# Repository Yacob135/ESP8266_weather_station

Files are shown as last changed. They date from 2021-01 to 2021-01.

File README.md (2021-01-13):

# ESP8266_weather_station

This weather station has an ESP8266-12F in combination with DS18B20 and/or BME280 for sensing. I used a TP4056 module for 18650 Li-Ion battery charging/protection and TPS63900 buck-boost converter, which has incredibly low quiescent current combined with great efficiency at low power consumption (>90% at 10uA).

The station connects to my local Blynk server and sends the data every 5 minutes. During deep-sleep the whole circuit consumes about 25uA, which is fantastic. It should last about a year on one charge, since it connects to my server, sends the data and goes back to sleep in about 0.7s on average (I used Blynk API to reduce the connection time). So the overall power consumption is really low.

Just a little warning when buying ESP8266-12F modules from aliexpress. Make sure to buy the Ai-Thinker version, since the "Espressif" version will have about 150uA in deep-sleep instead of 20uA. Learnt this the hard way.

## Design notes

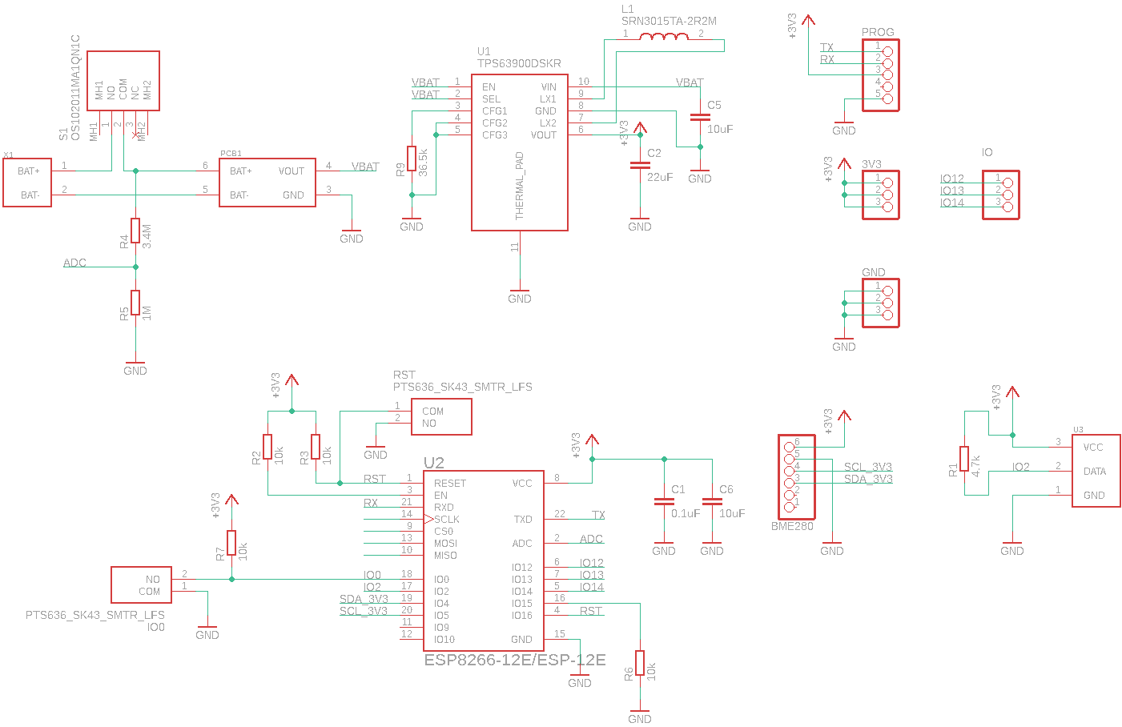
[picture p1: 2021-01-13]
ESP8266_weather_station_schematic.png

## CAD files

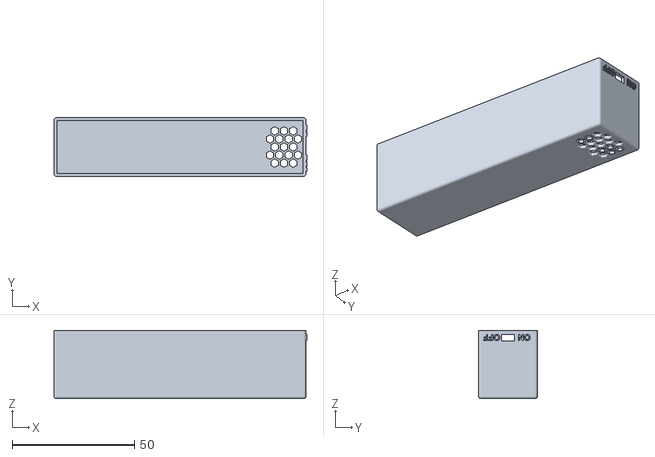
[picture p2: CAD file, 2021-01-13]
Main_body.stl
103.3 x 24.0 x 27.9

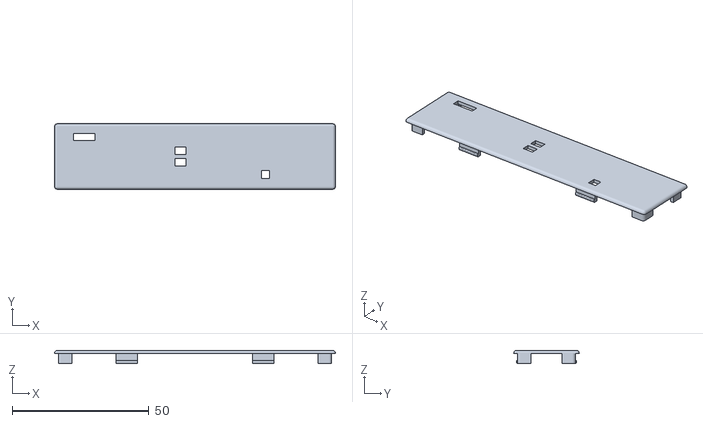
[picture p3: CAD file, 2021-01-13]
Top_cover.stl
102.9 x 24.0 x 4.80

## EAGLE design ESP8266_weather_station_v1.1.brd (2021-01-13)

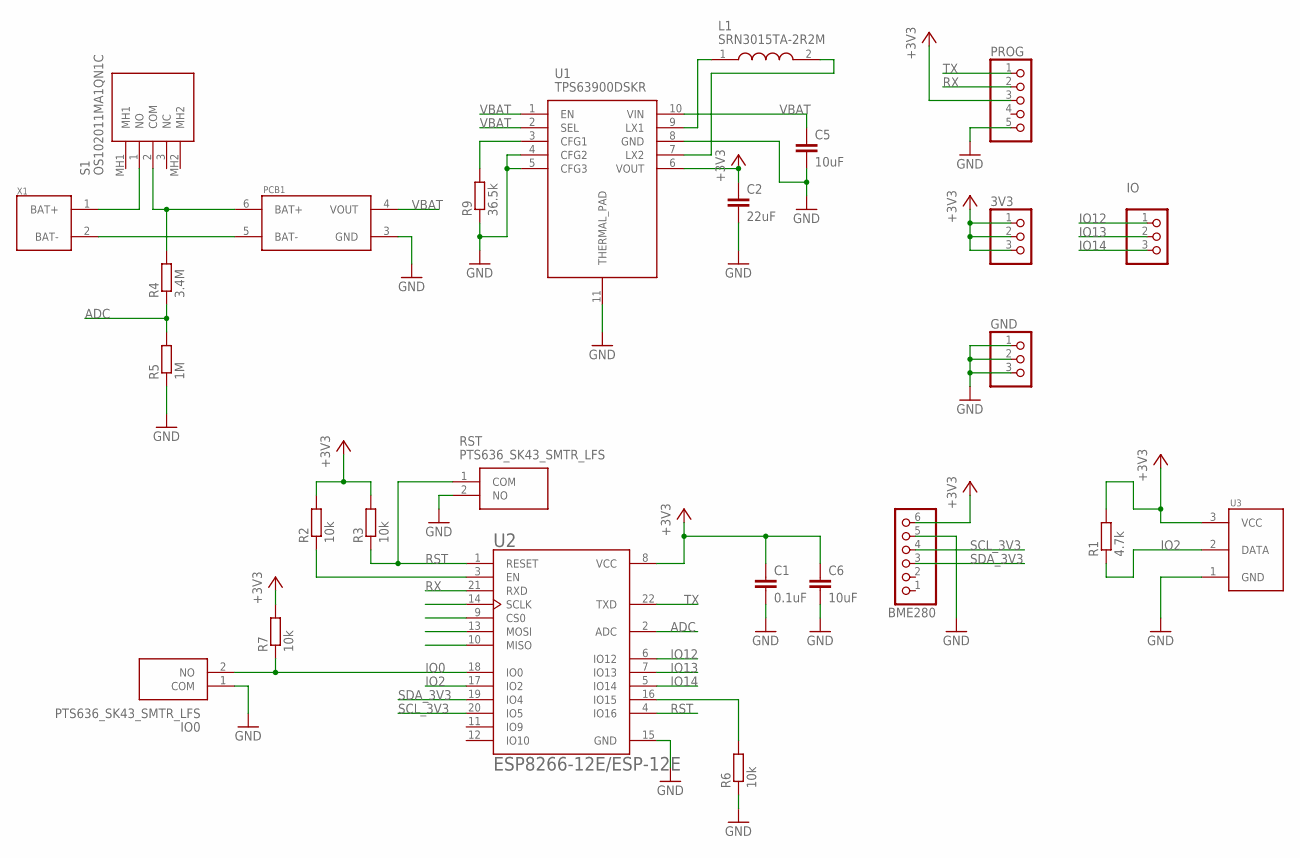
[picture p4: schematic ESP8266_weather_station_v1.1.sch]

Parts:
3V3: PINHD-1X3; 1X03
BME280: PINHD-1X6; 1X06
C1: 0.1uF; C0805
C2: 22uF; C0805
C5, C6: 10uF; C0805
GND: PINHD-1X3; 1X03
IO: PINHD-1X3; 1X03
IO0: PTS636_SK43_SMTR_LFS; PTS636SK43SMTRLFS
L1: SRN3015TA-2R2M; SRN3015TA2R2M
PCB1: TP4056_MODULE
PROG: PINHD-1X5; 1X05
R1: 4.7k; R0805
R2, R3, R6, R7: 10k; R0805
R4: 3.4M; R0805
R5: 1M; R0805
R9: 36.5k; R0805
RST: PTS636_SK43_SMTR_LFS; PTS636SK43SMTRLFS
S1: OS102011MA1QN1C
U1: TPS63900DSKR; SON50P250X250X80-11N
U2: ESP8266-12E/ESP-12E; XCVR_ESP8266-12E/ESP-12E
U3: DS18B20
X1: 18650_SMD_HOLDER

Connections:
+3V3: 3V3.1, 3V3.2, 3V3.3, BME280.6, C1.1, C2.1, C6.1, PROG.3, R1.2, R2.2, R3.2, R7.2, U1.6 (VOUT), U2.8 (VCC), U3.3 (VCC)
ADC: R4.1, R5.2, U2.2 (ADC)
GND: BME280.5, C1.2, C2.2, C5.2, C6.2, GND.1, GND.2, GND.3, IO0.1 (COM), PCB1.3 (GND), PROG.5, R5.1, R6.1, R9.1, RST.2 (NO), U1.4 (CFG2), U1.5 (CFG3), U1.8 (GND), U1.11 (THERMAL_PAD), U2.15 (GND), U3.1 (GND)
IO0: IO0.2 (NO), R7.1, U2.18 (IO0)
IO2: R1.1, U2.17 (IO2), U3.2 (DATA)
IO12: IO.1, U2.6 (IO12)
IO13: IO.2, U2.7 (IO13)
IO14: IO.3, U2.5 (IO14)
unnamed: S1.1 (NO), X1.1 (BAT+)
unnamed: R9.2, U1.3 (CFG1)
unnamed: PCB1.6 (BAT+), R4.2, S1.2 (COM)
unnamed: PCB1.5 (BAT-), X1.2 (BAT-)
unnamed: R6.2, U2.16 (IO15)
unnamed: L1.1, U1.9 (LX1)
unnamed: L1.2, U1.7 (LX2)
unnamed: R2.1, U2.3 (EN)
RST: R3.1, RST.1 (COM), U2.1 (RESET), U2.4 (IO16)
RX: PROG.2, U2.21 (RXD)
SCL_3V3: BME280.4, U2.20 (IO5)
SDA_3V3: BME280.3, U2.19 (IO4)
TX: PROG.1, U2.22 (TXD)
VBAT: C5.1, PCB1.4 (VOUT), U1.1 (EN), U1.2 (SEL), U1.10 (VIN)

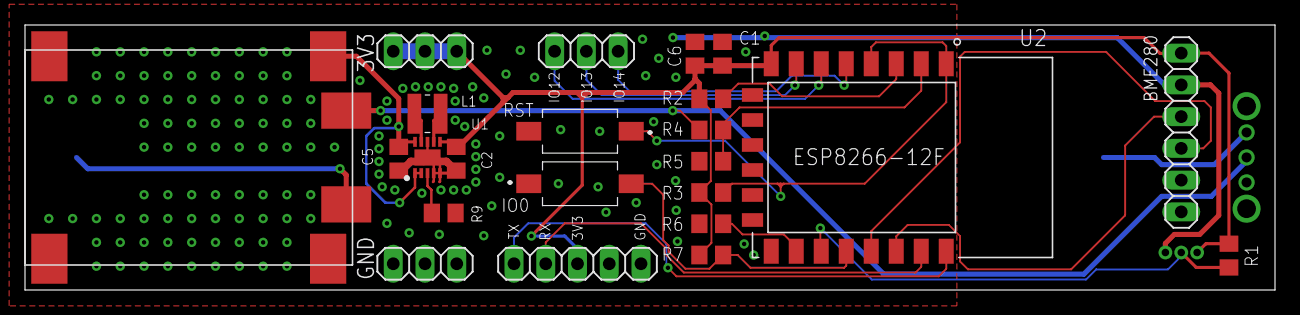
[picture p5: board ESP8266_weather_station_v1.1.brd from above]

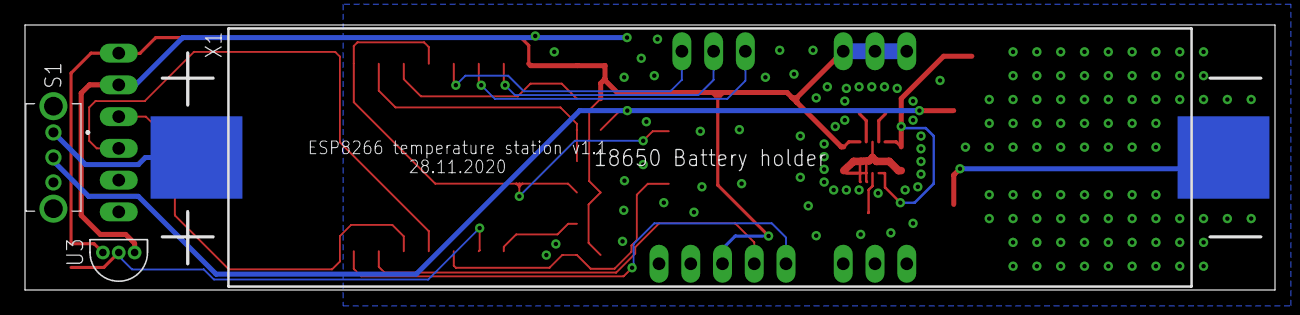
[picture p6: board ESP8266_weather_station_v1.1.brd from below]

Board: 2 copper layers, 100.0 x 21.2 mm, 26 parts (3 on the bottom side), 22 nets.

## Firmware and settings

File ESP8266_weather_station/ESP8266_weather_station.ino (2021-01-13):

#include <ESP8266WiFi.h>
#include <ESP8266HTTPClient.h>
#include <Wire.h>
#include <Adafruit_Sensor.h>
#include <Adafruit_BME280.h>

#define SEALEVELPRESSURE_HPA (1013.25)

Adafruit_BME280 bme;

const char* ssid = "your_ssid_here";
const char* password = "your_pass_here";

#include <OneWire.h>
#include <DallasTemperature.h>

#define ONE_WIRE_BUS 2

OneWire oneWire(ONE_WIRE_BUS);
DallasTemperature DS18B20(&oneWire);

void setup () {

  Serial.begin(115200);

  Wire.begin(4, 5);
  bme.begin(0x76);

  bme.setSampling(Adafruit_BME280::MODE_FORCED,
                  Adafruit_BME280::SAMPLING_X1,
                  Adafruit_BME280::SAMPLING_X1,
                  Adafruit_BME280::SAMPLING_X1,
                  Adafruit_BME280::FILTER_OFF);

  DS18B20.begin();

  uint16_t wifiTime = 0;
  WiFi.begin(ssid, password);
  while (WiFi.status() != WL_CONNECTED) {
    delay(10);
    wifiTime++;
    if (wifiTime > 1000) {
      break; //breaks the loop after 10 seconds of unsuccessful connection
    }
  }

}

void loop() {
  if (WiFi.status() == WL_CONNECTED) {

    HTTPClient http;

    String stringVal;
    String httpReq;
    String payload;
    int httpCode;


    DS18B20.requestTemperatures();
    float temp = DS18B20.getTempCByIndex(0);

    if (temp > -80.0 && temp < 80.0) {
      stringVal = String(temp, 3);
      httpReq = String("http://your_server_here:8080/your_auth_token_here/update/V1?value=" + stringVal);
      http.begin(httpReq);
      httpCode = http.GET();
    }

    float bmeTemperature;
    float bmePressure;
    float bmeHumidity;

    bme.takeForcedMeasurement();
    bmeTemperature = bme.readTemperature();
    bmeHumidity = bme.readHumidity();
    bmePressure = bme.readPressure() / 100.0F;

    stringVal = String(bmeTemperature, 3);
    httpReq = String("http://your_server_here:8080/your_auth_token_here/update/V2?value=" + stringVal);
    http.begin(httpReq);  //Specify request destination
    httpCode = http.GET();

    stringVal = String(bmeHumidity, 3);
    httpReq = String("http://your_server_here:8080/your_auth_token_here/update/V3?value=" + stringVal);
    http.begin(httpReq);  //Specify request destination
    httpCode = http.GET();

    stringVal = String(bmePressure, 3);
    httpReq = String("http://your_server_here:8080/your_auth_token_here/update/V4?value=" + stringVal);
    http.begin(httpReq);  //Specify request destination
    httpCode = http.GET();

    float batteryVoltage = analogRead(A0) / 1024.0 * 4.4;
    stringVal = String(batteryVoltage, 2);
    httpReq = String("http://your_server_here:8080/your_auth_token_here/update/V5?value=" + stringVal);
    http.begin(httpReq);  //Specify request destination
    httpCode = http.GET();

    int16_t batteryPercentage = 389.344 - (288.378 * batteryVoltage) + (53.4812 * batteryVoltage * batteryVoltage);
    if (batteryPercentage >= 100) {
      batteryPercentage = 100;
    }
    if (batteryPercentage <= 0) {
      batteryPercentage = 0;
    }
    stringVal = batteryPercentage;
    httpReq = String("http://your_server_here:8080/your_auth_token_here/update/V6?value=" + stringVal);
    http.begin(httpReq);  //Specify request destination
    httpCode = http.GET();

    stringVal = String(millis());
    httpReq = String("http://your_server_here:8080/your_auth_token_here/update/V7?value=" + stringVal);
    http.begin(httpReq);  //Specify request destination
    httpCode = http.GET();

    http.end();   //Close connection
  }

  ESP.deepSleep(5 * 60e6);
}
